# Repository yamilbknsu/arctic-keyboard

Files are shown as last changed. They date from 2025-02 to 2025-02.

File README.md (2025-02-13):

# ❄️ <span style="background: linear-gradient(rgb(33, 103, 243),rgb(18, 237, 252));-webkit-text-fill-color: transparent; -webkit-background-clip:text;">Arctic</span> - Split Keyboard

Repo structure:
- `ergogen` folder: [ergogen](https://github.com/ergogen/ergogen) config file and community footprints used
- `pcbs` folder: Finished KiCAD PCB files for left and right plates as well as SVG file used for designing the case
- `case` folder: `obj` file used to generate `.3MF` for 3D printed case.
- `config`, `build.yaml` and `zephyr`: [ZMK](https://zmk.dev/) firmware files for nice!nanov2 MCU

## Assembled Keyboard
Arctic assembled

## Materials
| Name | Qty | Reference |
|---|-----|---|
| PCB Plates | 2 | One for each side |
| 3D Printed case | 1 | Four parts in total |
| MX Switches | 64  | From [Typeractive.xyz](https://typeractive.xyz/products/jwk-jwick-t1-tactile-switches) |
| MX Black Keycaps | 52  | From [nuphy.com](https://nuphy.com/collections/keycaps/products/gem-msa) |
| MX White Keycaps | 12  | From [Amazon](https://www.amazon.com/dp/B0CBR6XFBY) |
| nice!nano v2.0 | 2 | From [Typeractive.xyz](https://typeractive.xyz/products/nice-nano) |
| SMD Diodes | 64  | From [Typeractive.xyz](https://typeractive.xyz/products/smd-diodes) |
| Kailh Hotswap Sockets  | 64  | From [Typeractive.xyz](https://typeractive.xyz/products/hotswap-sockets) |
| Reset Button | 2 | From [Typeractive.xyz](https://typeractive.xyz/products/reset-button) |
| Power Switch | 2 | From [Typeractive.xyz](https://typeractive.xyz/products/power-switch) |
| Battery Jack | 2 | From [Typeractive.xyz](https://typeractive.xyz/products/battery-jack) |
| Lithium Battery 750mAh | 2 | From [Typeractive.xyz](https://typeractive.xyz/products/lithium-battery-750mah) |
| EZ-Solder Sockets (Opt)| 2 | From [Typeractive.xyz](https://typeractive.xyz/products/ez-machine-sockets-and-headers)|
| 2mm Rubber Feet (Opt)  | 10  | From [Typeractive.xyz](https://www.amazon.com/dp/B06XCNM69B) |
| EZ-Solder Sockets (Opt)| 2 | From [Typeractive.xyz](https://typeractive.xyz/products/ez-machine-sockets-and-headers)|
| M2 Screws and separator| 20  | 10 6mm M2 + 10 4mm M2 and 10 4mm M2 separators |

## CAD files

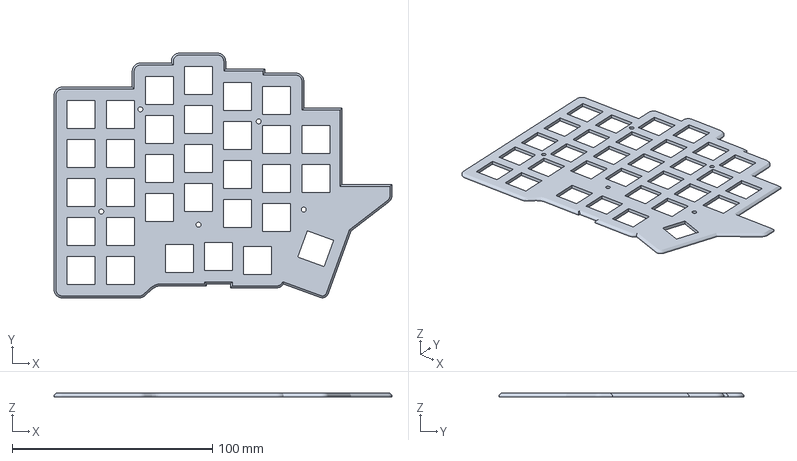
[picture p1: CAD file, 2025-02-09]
case/3MF Files/ArcticCasev1.10 - LeftPlate.3mf
168.9 x 122.3 x 1.80 mm

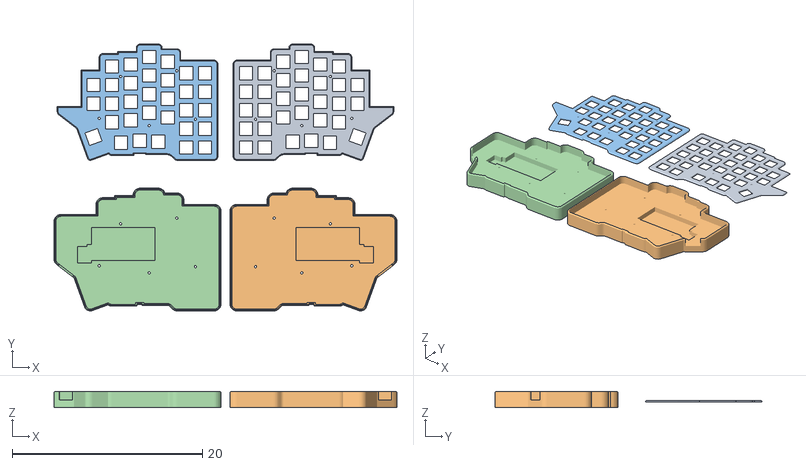
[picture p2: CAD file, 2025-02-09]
case/ArcticCasev1.10.obj
36.1 x 28.1 x 1.73
LeftPlate
LeftCase
RightPlate
RightCase

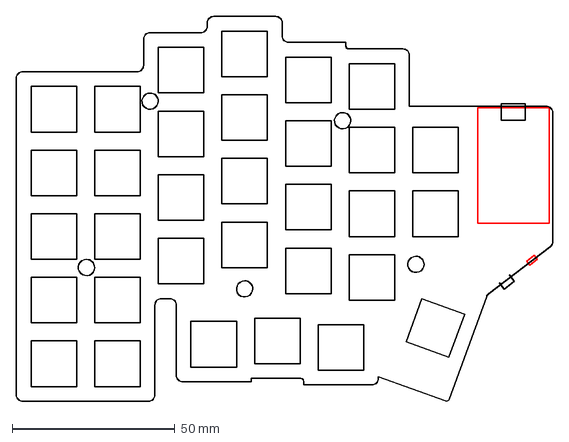
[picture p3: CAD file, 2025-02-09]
pcbs/left_case_top.svg/left_case-brd.dxf
164.8 x 118.3 mm

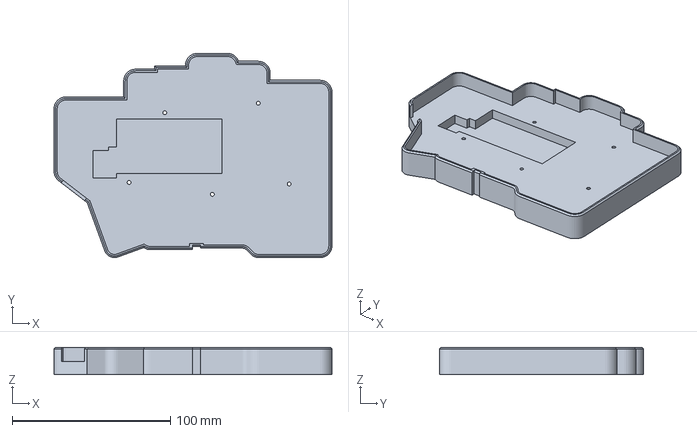
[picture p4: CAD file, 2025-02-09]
case/3MF Files/ArcticCasev1.10 - RightCase.3mf
175.8 x 129.2 x 17.3 mm

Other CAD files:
case/3MF Files/ArcticCasev1.10 - LeftCase.3mf
case/3MF Files/ArcticCasev1.10 - RightPlate.3mf

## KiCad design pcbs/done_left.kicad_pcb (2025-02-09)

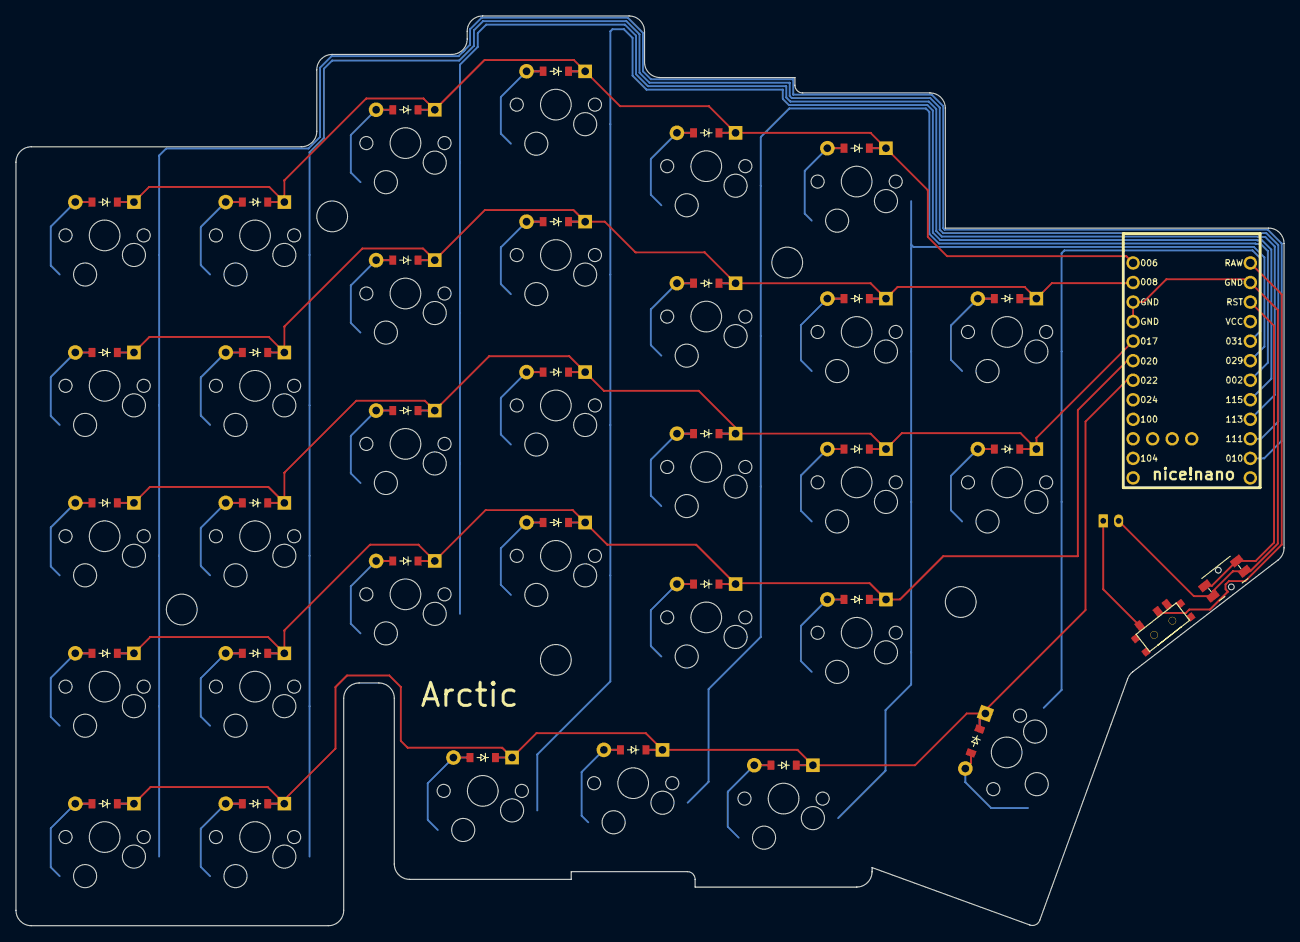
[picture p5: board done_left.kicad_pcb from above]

Board: 2 copper layers, 164.8 x 118.2 mm, 68 parts (0 on the bottom side), 48 nets.

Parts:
B1: Panasonic_EVQPUL_EVQPUC
D1, D2, D3, D4, D5, D6, D7, D8, D9, D10, D11, D12, D13, D14, D15, D16, D17, D18, D19, D20, D21, D22, D23, D24, D25, D26, D27, D28, D29, D30, D31, D32: ComboDiode
JST1: JST_PH_S2B-PH-K_02x2.00mm_Angled
MCU1: nice_nano
S1, S2, S3, S4, S5, S6, S7, S8, S9, S10, S11, S12, S13, S14, S15, S16, S17, S18, S19, S20, S21, S22, S23, S24, S25, S26, S27, S28, S29, S30, S31, S32: MX
T1: SPDT_C128955

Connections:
GND: B1.1, JST1.2, MCU1.3, MCU1.4, MCU1.23
P002: MCU1.18, S19.1, S20.1, S21.1, S22.1, S30.1
P006: D5.1, D10.1, D14.1, D18.1, D22.1, D26.1, MCU1.1
P008: D4.1, D9.1, D13.1, D17.1, D21.1, D25.1, D28.1, MCU1.2
P010: MCU1.14, S1.1, S2.1, S3.1, S4.1, S5.1
P017: D3.1, D8.1, D12.1, D16.1, D20.1, D24.1, D27.1, MCU1.5
P020: D2.1, D7.1, D11.1, D15.1, D19.1, D23.1, MCU1.6
P022: D1.1, D6.1, D29.1, D30.1, D31.1, D32.1, MCU1.7
P029: MCU1.19, S23.1, S24.1, S25.1, S26.1, S31.1
P031: MCU1.20, S27.1, S28.1, S32.1
P111: MCU1.15, S6.1, S7.1, S8.1, S9.1, S10.1
P113: MCU1.16, S11.1, S12.1, S13.1, S14.1
P115: MCU1.17, S15.1, S16.1, S17.1, S18.1, S29.1
RAW: MCU1.24, T1.2
RST: B1.2, MCU1.22
actions_bottom: D2.2, S2.2
actions_home: D3.2, S3.2
actions_modifiers: D1.2, S1.2
actions_numbers: D5.2, S5.2
actions_top: D4.2, S4.2
back_thumb: D29.2, S29.2
forward_thumb: D32.2, S32.2
index_bottom: D19.2, S19.2
index_home: D20.2, S20.2
index_numbers: D22.2, S22.2
index_top: D21.2, S21.2
inner_bottom: D23.2, S23.2
inner_home: D24.2, S24.2
inner_numbers: D26.2, S26.2
inner_top: D25.2, S25.2
middle_bottom: D15.2, S15.2
middle_home: D16.2, S16.2
middle_numbers: D18.2, S18.2
middle_thumb: D30.2, S30.2
middle_top: D17.2, S17.2
pinky_bottom: D7.2, S7.2
pinky_home: D8.2, S8.2
pinky_modifiers: D6.2, S6.2
pinky_numbers: D10.2, S10.2
pinky_top: D9.2, S9.2
pos: JST1.1, T1.1
ring_bottom: D11.2, S11.2
ring_home: D12.2, S12.2
ring_numbers: D14.2, S14.2
ring_top: D13.2, S13.2
space_thumb: D31.2, S31.2
special_home: D27.2, S27.2
special_top: D28.2, S28.2
